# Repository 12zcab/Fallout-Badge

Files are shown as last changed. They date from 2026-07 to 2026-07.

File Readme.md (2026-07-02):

# Soupa Cool Badge for FallOut:D

Erm yah why not build a Badge with Z80 instead of ESP32 :)

Slack Username:12zcab

# What it can do?

1.Display ur Detail on 1602 LCD

2.use joystick and 6 Buttons to control the device

3.Plug it onto ur computer and have more interaction through console!

AND THE MOST IMPORTANT POINT IS: ITS HACKABLE!!!!!!!!!

U can easily reprogram it by overriding data on the EEPROM

# Main Components
Pls refer to BOM.csv for more details
1.Z80 10MHz
2.Z80 PIO 10MHz IC
3.MS6850 Serial IC
4.WC1602A LCD Display
5.Push Buttons
6.5 Direction Mini Joystick
7.on Board CH340

# Images

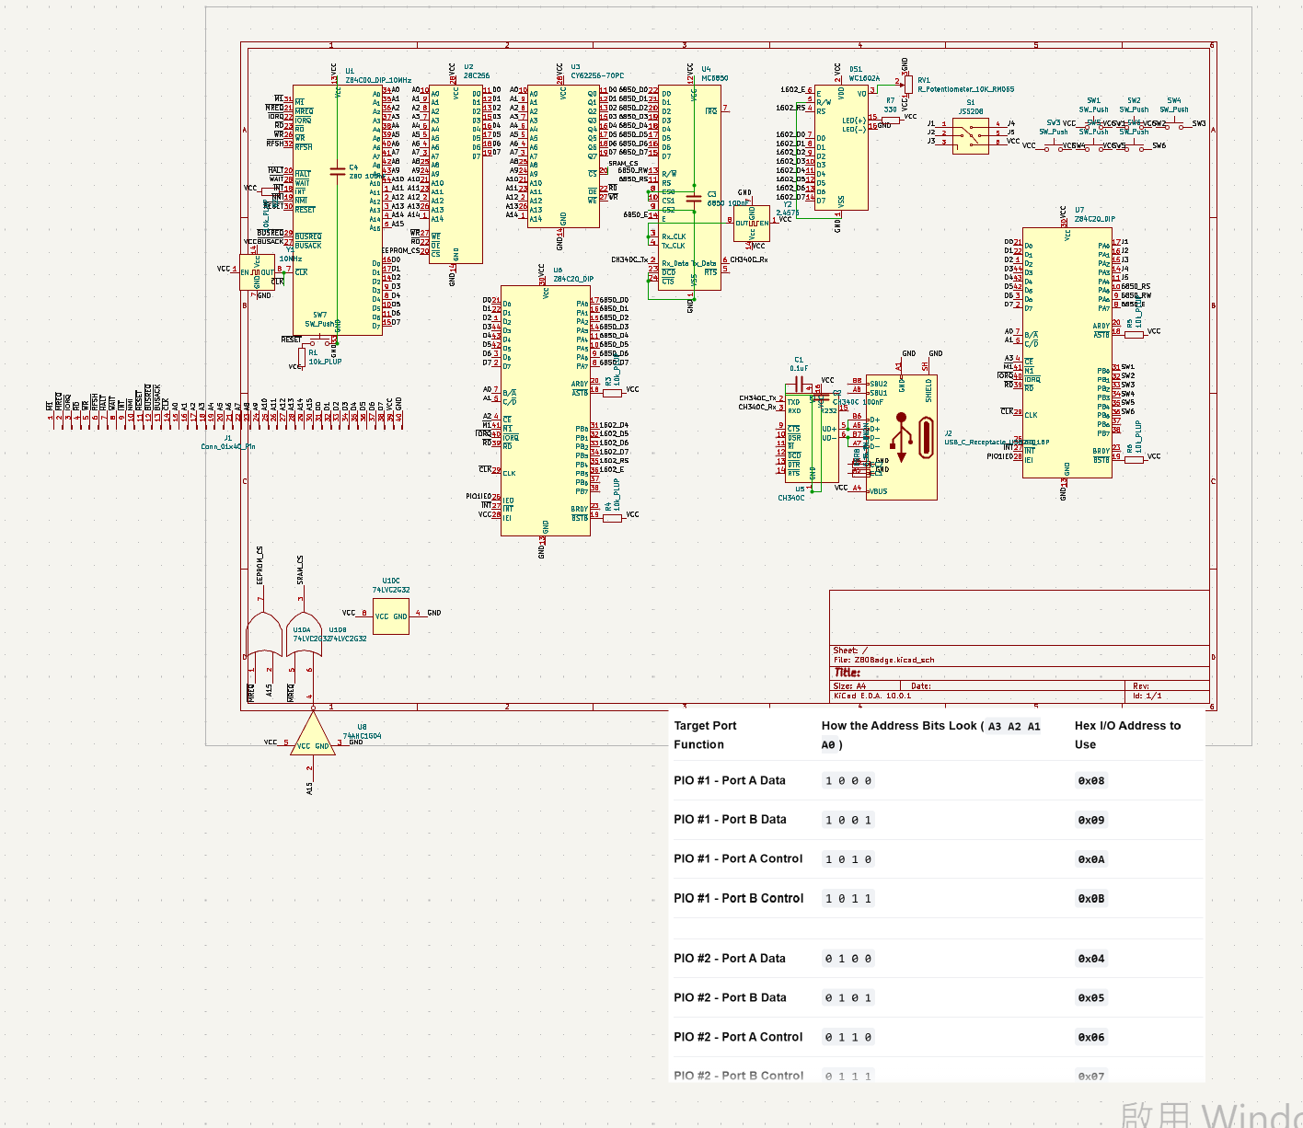
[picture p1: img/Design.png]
Design


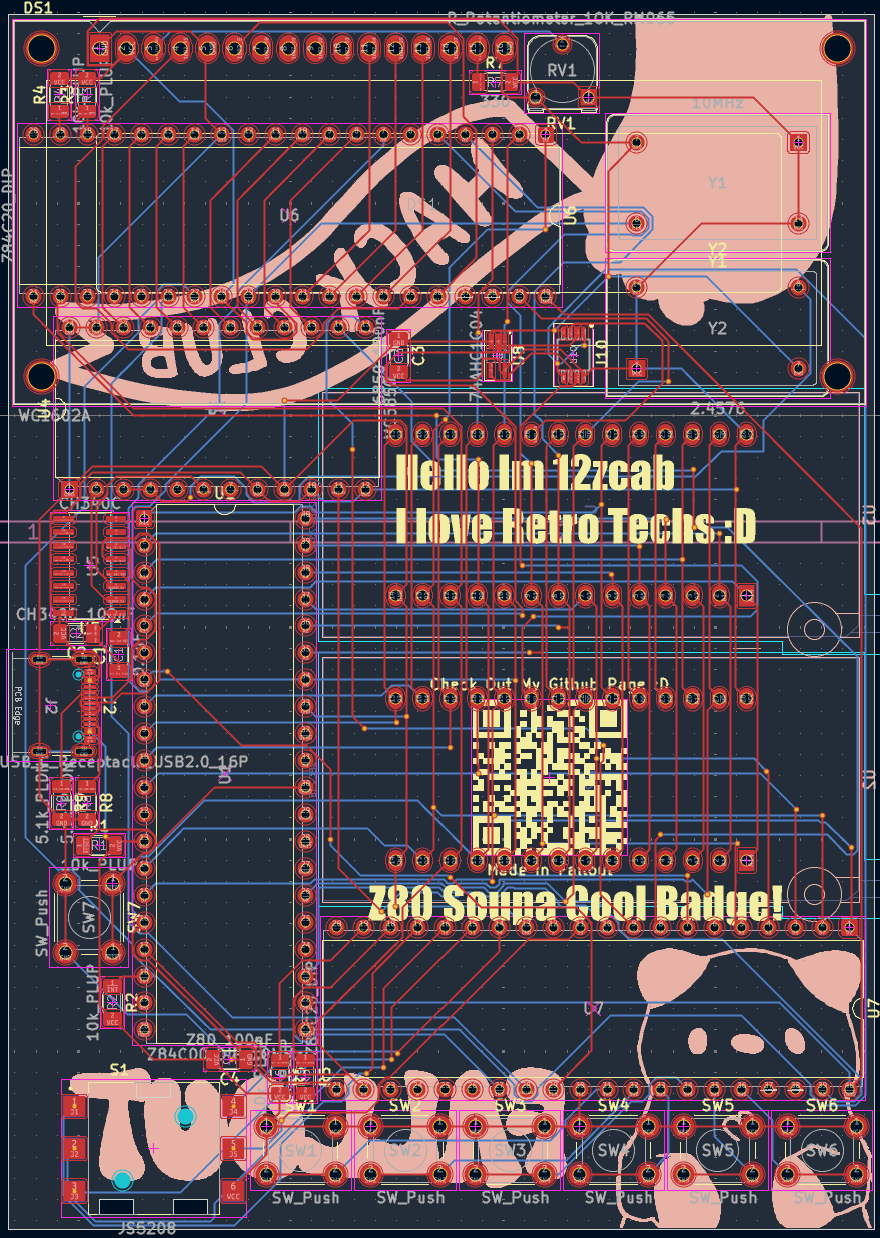
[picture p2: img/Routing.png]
Routing


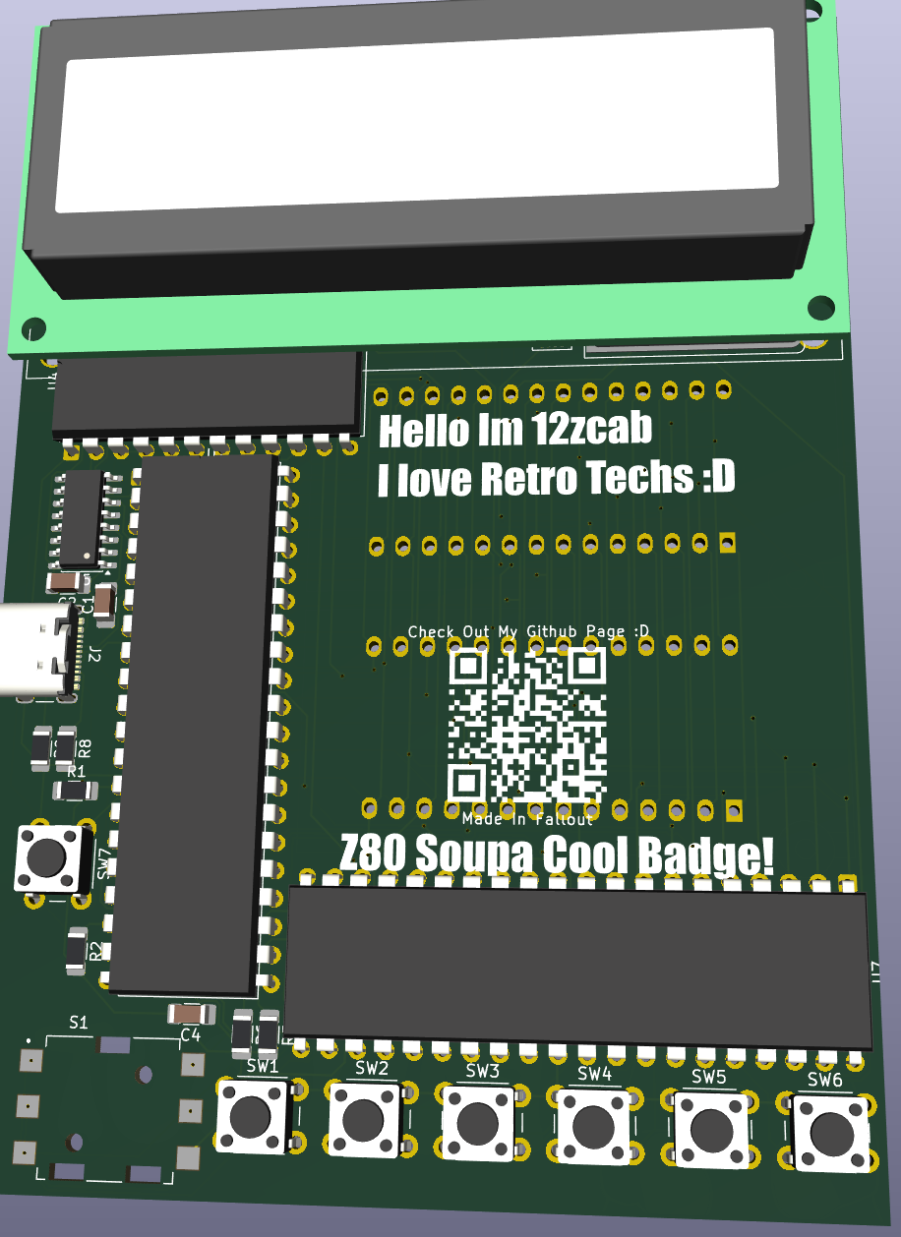
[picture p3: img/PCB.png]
PCB


PCB-Order-Page

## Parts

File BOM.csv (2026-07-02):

Item Name | Item Quantity | Item Link | Item Unit Price | Item Price(RMB) | Price In USD
Capa 100nF 1206 | 4 | https://detail.tmall.com/item.htm?id=592764875280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 | NOT APPLIABLE | 4.95
WC1602A | 1 | https://item.taobao.com/item.htm?ali_trackid=282_47943c4e9544049cca0f72b199db7b70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 | NOT APPLIABLE | 5.3
USB C 6P SMD | 1 | https://item.taobao.com/item.htm?id=990070098529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 | 4.8 | 4.8
Resis 10k 1206 | 6 | https://item.taobao.com/item.htm?id=948014405380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 | NOT APPLIABLE | 1.5
Resis 330 1206 | 1 | https://item.taobao.com/item.htm?id=948014405380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 | NOT APPLIABLE | 1.5
Resis 5.1k 1206 | 2 | https://item.taobao.com/item.htm?id=948014405380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 | NOT APPLIABLE | 1.5
RM065 Potentio SMD 10k | 1 | https://item.taobao.com/item.htm?ali_trackid=282_178754382f306b094bdb580dd3a8b003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 | 1.4 | 1.4
JS5208 | 1 | https://item.taobao.com/item.htm?id=739043147728&skuId=5096271028949 | 2.2 | 2.2
SW 6mm THT | 7 | https://item.taobao.com/item.htm?id=1021276117454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 | NOT APPLIABLE | 2.8
Z84C00 DIP | 1 | https://item.taobao.com/item.htm?id=608875850524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 | 4.5 | 4.5
28C256 DIP | 1 | https://item.taobao.com/item.htm?id=39532371153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 | 16.5 | 16.5
CY62256 DIP | 1 | https://item.taobao.com/item.htm?id=1048236230258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 | 4 | 4
MC6850 | 1 | https://item.taobao.com/item.htm?id=774768319105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 | 2.98 | 2.98
CH340C | 1 | https://detail.tmall.com/item.htm?id=969941374446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 | 2.2 | 2.2
Z84C20 DIP | 2 | https://item.taobao.com/item.htm?id=761218301763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 | 5.5 | 11
74AHC1G04 | 1 | https://item.taobao.com/item.htm?id=1056972037441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 | 0.26 | 0.26
74LVC2G32 | 1 | https://item.taobao.com/item.htm?ali_trackid=282_a1cc07042d99c9e791c237e71c7924dd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 | 1.08 | 1.08
10MHz Crystal | 1 | https://item.taobao.com/item.htm?id=594658769726&from=cart&skuId=4463870019686&upStreamPrice=495 | 4.95 | 4.95
2.4576 Crystal | 1 | https://item.taobao.com/item.htm?id=594658769726&from=cart&skuId=4463870019686&upStreamPrice=495 | 4.95 | 4.95
DIP Sockets | 2 | https://detail.tmall.com/item.htm?id=14119412637&skuId=5061116598157 | 4.27 | 8.54
OverAll |  |  |  | 86.91 | 13.0365
PCB |  |  |  | Dunno | Dunno

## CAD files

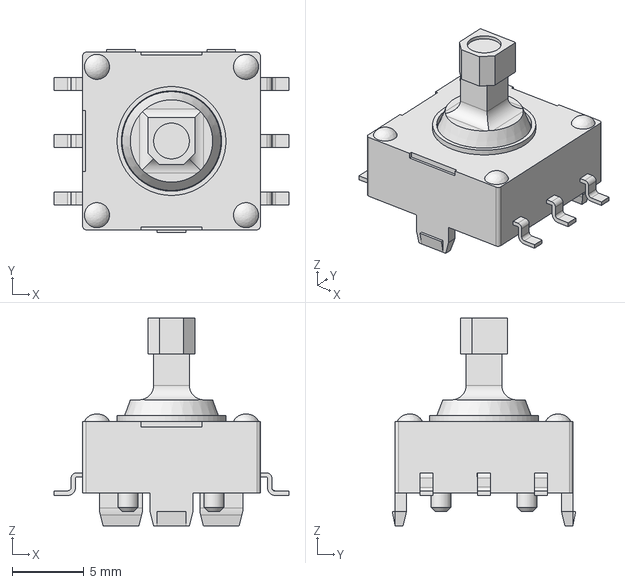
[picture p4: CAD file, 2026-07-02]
JS5208/JS5208.step
16.4 x 12.8 x 14.5 mm

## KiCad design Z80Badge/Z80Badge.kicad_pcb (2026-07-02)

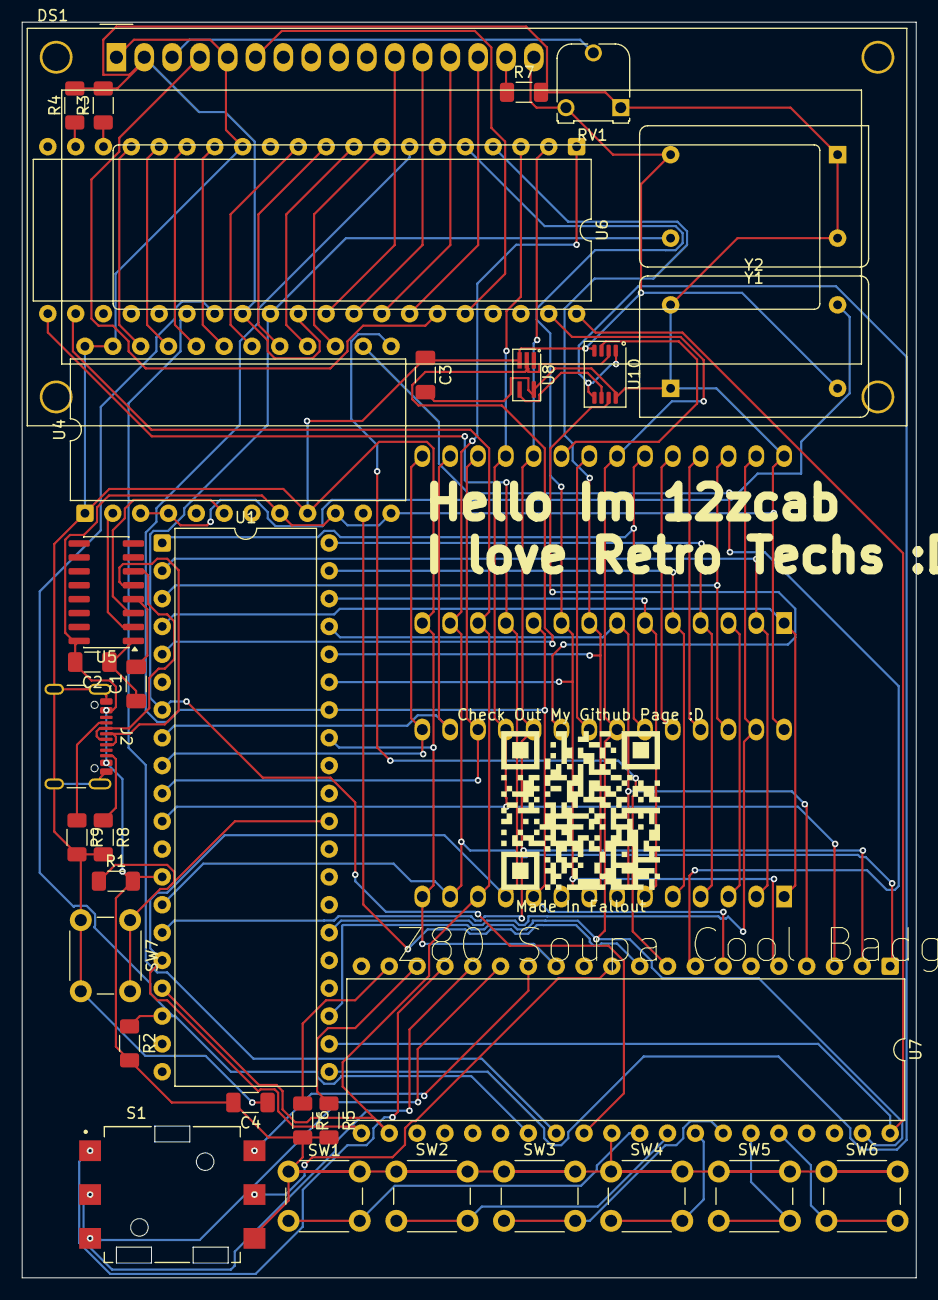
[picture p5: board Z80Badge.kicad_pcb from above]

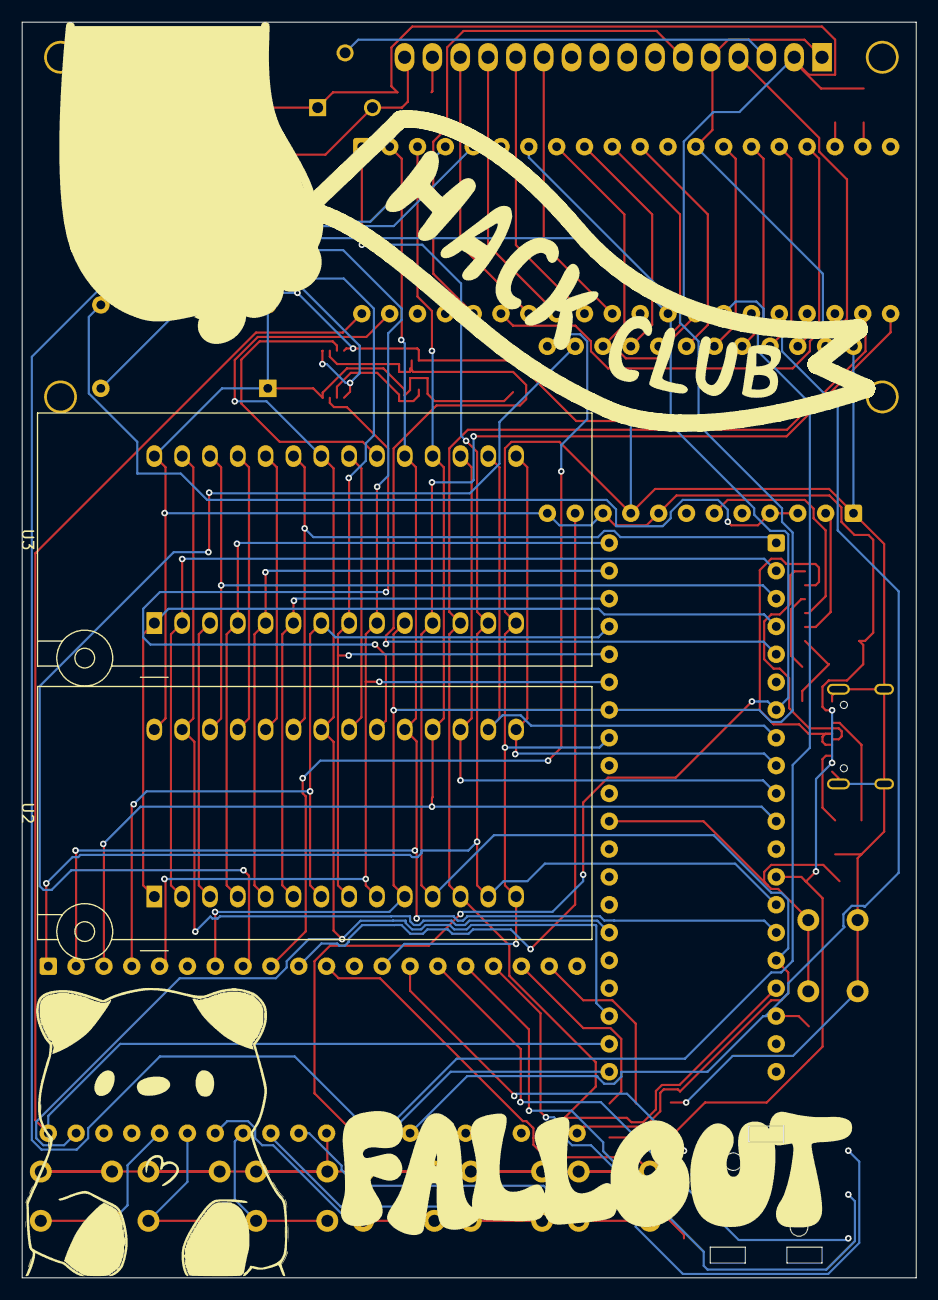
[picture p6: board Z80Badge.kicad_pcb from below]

Board: 2 copper layers, 81.6 x 114.6 mm, 36 parts (2 on the bottom side), 80 nets.

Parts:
C1: 0.1uF; C_1206_3216Metric_Pad1.33x1.80mm_HandSolder
C2: CH340C 100nF; C_1206_3216Metric_Pad1.33x1.80mm_HandSolder
C3: 6850 100nF; C_1206_3216Metric_Pad1.33x1.80mm_HandSolder
C4: Z80 100nF; C_1206_3216Metric_Pad1.33x1.80mm_HandSolder
DS1: WC1602A
J2: USB_C_Receptacle_USB2.0_16P; USB_C_Receptacle_GCT_USB4105-xx-A_16P_TopMnt_Horizontal
Made In Fallout: Check Out My Github Page :D; //github.com/12zcab?tab=repositories
R1, R2, R3, R4, R5, R6: 10k_PLUP; R_1206_3216Metric_Pad1.30x1.75mm_HandSolder
R7: 330; R_1206_3216Metric_Pad1.30x1.75mm_HandSolder
R8, R9: 5.1k_PLDN; R_1206_3216Metric_Pad1.30x1.75mm_HandSolder
RV1: R_Potentiometer_10K_RM065; Potentiometer_Runtron_RM-065_Vertical
S1: JS5208; SW_JS5208
SW1, SW2, SW3, SW4, SW5, SW6, SW7: SW_Push; SW_PUSH_6mm
U1: Z84C00_DIP_10MHz; DIP-40_W15.24mm
U2: 28C256; DIP_Socket-28_W11.9mm_W12.7mm_W15.24mm_W17.78mm_W18.5mm_3M_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
U3: CY62256-70PC; DIP_Socket-28_W11.9mm_W12.7mm_W15.24mm_W17.78mm_W18.5mm_3M_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
U4: MC6850; DIP-24_W15.24mm
U5: CH340C; SOIC-16_3.9x9.9mm_P1.27mm
U6, U7: Z84C20_DIP; DIP-40_W15.24mm
U8: 74AHC1G04; SOT-353_SC-70-5_Handsoldering
U10: 74LVC2G32; TSSOP-8_3x3mm_P0.65mm
Y1: 10MHz; Oscillator_DIP-14
Y2: 2.4576; Oscillator_DIP-14

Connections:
/1602_D4: DS1.11 (D4), U6.31 (PB_{0})
/1602_D5: DS1.12 (D5), U6.32 (PB_{1})
/1602_D6: DS1.13 (D6), U6.33 (PB_{2})
/1602_D7: DS1.14 (D7), U6.34 (PB_{3})
/1602_E: DS1.6 (E), U6.36 (PB_{5})
/1602_RS: DS1.4 (RS), U6.35 (PB_{4})
/6850_D0: U4.22 (D0), U6.17 (PA_{0})
/6850_D1: U4.21 (D1), U6.16 (PA_{1})
/6850_D2: U4.20 (D2), U6.15 (PA_{2})
/6850_D3: U4.19 (D3), U6.14 (PA_{3})
/6850_D4: U4.18 (D4), U6.11 (PA_{4})
/6850_D5: U4.17 (D5), U6.10 (PA_{5})
/6850_D6: U4.16 (D6), U6.9 (PA_{6})
/6850_D7: U4.15 (D7), U6.8 (PA_{7})
/6850_E: U4.14 (E), U7.8 (PA_{7})
/6850_RS: U4.11 (RS), U7.10 (PA_{5})
/6850_RW: U4.13 (R/~W), U7.9 (PA_{6})
/A0: U1.34 (A_{0}), U2.10 (A0), U3.10 (A0), U6.7 (B/~A), U7.7 (B/~A)
/A1: U1.35 (A_{1}), U2.9 (A1), U3.9 (A1), U6.5 (C/~D), U7.5 (C/~D)
/A2: U1.36 (A_{2}), U2.8 (A2), U3.8 (A2), U6.4 (~CE)
/A3: U1.37 (A_{3}), U2.7 (A3), U3.7 (A3), U7.4 (~CE)
/A4: U1.38 (A_{4}), U2.6 (A4), U3.6 (A4)
/A5: U1.39 (A_{5}), U2.5 (A5), U3.5 (A5)
/A6: U1.40 (A_{6}), U2.4 (A6), U3.4 (A6)
/A7: U2.3 (A7), U3.3 (A7)
/A8: U2.25 (A8), U3.25 (A8)
/A9: U2.24 (A9), U3.24 (A9)
/A10: U2.21 (A10), U3.21 (A10)
/A11: U1.1 (A_{11}), U2.23 (A11), U3.23 (A11)
/A12: U1.2 (A_{12}), U2.2 (A12), U3.2 (A12)
/A13: U1.3 (A_{13}), U2.26 (A13), U3.26 (A13)
/A14: U1.4 (A_{14}), U2.1 (A14), U3.1 (A14)
/A15: U1.5 (A_{15}), U8.2, U10.2
/CH340C_Rx: U4.6 (Tx_Data), U5.3 (RXD)
/CH340C_Tx: U4.2 (Rx_Data), U5.2 (TXD)
/D0: U1.16 (D_{0}), U2.11 (D0), U3.11 (Q0), U6.21 (D_{0}), U7.21 (D_{0})
/D1: U1.17 (D_{1}), U2.12 (D1), U3.12 (Q1), U6.22 (D_{1}), U7.22 (D_{1})
/D2: U1.14 (D_{2}), U2.13 (D2), U3.13 (Q2), U6.1 (D_{2}), U7.1 (D_{2})
/D3: U1.9 (D_{3}), U2.15 (D3), U3.15 (Q3)
/D4: U1.8 (D_{4}), U2.16 (D4), U3.16 (Q4)
/D5: U1.10 (D_{5}), U2.17 (D5), U3.17 (Q5)
/D6: U1.11 (D_{6}), U2.18 (D6), U3.18 (Q6), U6.3 (D_{6}), U7.3 (D_{6})
/D7: U1.15 (D_{7}), U2.19 (D7), U3.19 (Q7), U6.2 (D_{7}), U7.2 (D_{7})
/EEPROM_CS: U2.20 (~CS), U10.7
/GND: C3.1, C4.1, DS1.1 (VSS), DS1.5 (R/W), DS1.16 (LED(-)), J2.A1 (GND), J2.A12 (GND), J2.B1 (GND), J2.B12 (GND), J2.SH (SHIELD), R8.2, R9.2, RV1.3, SW7.2, U1.33 (GND), U2.14 (GND), U3.14 (GND), U4.1 (VSS), U4.9 (CS2), U4.23 (~DCD), U4.24 (~CTS), U6.13 (GND), U7.13 (GND), U8.3 (GND), U10.4 (GND), Y1.7 (GND), Y2.7 (GND)
/J1: S1.1, U7.17 (PA_{0})
/J2: S1.2, U7.16 (PA_{1})
/J3: S1.3, U7.15 (PA_{2})
/J4: S1.4, U7.14 (PA_{3})
/J5: S1.5, U7.11 (PA_{4})
/PIO1IE0: U6.26 (IEO), U7.28 (IEI)
/SRAM_CS: U3.20 (~CS), U10.3
/SW1: SW1.2, U7.31 (PB_{0})
/SW2: SW2.2, U7.32 (PB_{1})
/SW3: SW4.2, U7.33 (PB_{2})
/SW4: SW3.2, U7.34 (PB_{3})
/SW5: SW5.2, U7.35 (PB_{4})
/SW6: SW6.2, U7.36 (PB_{5})
/VCC: C2.2, C3.2, C4.2, DS1.2 (VDD), J2.A4 (VBUS), J2.A9 (VBUS), J2.B4 (VBUS), J2.B9 (VBUS), R1.2, R2.2, R3.2, R4.2, R5.2, R6.2, R7.2, RV1.1, S1.6, SW1.1, SW2.1, SW3.1, SW4.1, SW5.1, SW6.1, U1.13 (V_{CC}), U2.28 (VCC), U3.28 (VCC), U4.8 (CS0), U4.10 (CS1), U4.12 (VCC), U5.16 (VCC), U6.28 (IEI), U6.30 (V_{CC}), U7.30 (V_{CC}), U8.5 (VCC), U10.8 (VCC), Y1.1 (EN), Y1.14 (Vcc), Y2.1 (EN), Y2.14 (Vcc)
/~CLK: U1.7 (~CLK), U6.29 (CLK), U7.29 (CLK), Y1.8 (OUT)
/~INT: R2.1, U1.18 (~INT), U6.27 (~INT), U7.27 (~INT)
/~IORQ: U1.22 (~IORQ), U6.40 (~IORQ), U7.40 (~IORQ)
/~MREQ: U1.21 (~MREQ), U10.1, U10.5
/~RD: U1.23 (~RD), U2.22 (~OE), U3.22 (~OE), U6.39 (~RD), U7.39 (~RD)
/~RESET: R1.1, SW7.1, U1.30 (~RESET)
/~WR: U1.26 (~WR), U2.27 (~WE), U3.27 (~WE)
unnamed: DS1.15 (LED(+)), R7.1
unnamed: DS1.3 (VO), RV1.2
unnamed: J2.A5 (CC1), R9.1
unnamed: J2.B5 (CC2), R8.1
unnamed: U4.3 (Rx_CLK), U4.4 (Tx_CLK), Y2.8 (OUT)
unnamed: C1.1, C2.1, U5.1 (GND)
unnamed: J2.A6 (D+), J2.B6 (D+), U5.5 (UD+)
unnamed: J2.A7 (D-), J2.B7 (D-), U5.6 (UD-)
unnamed: C1.2, U5.4 (V3)
unnamed: R3.1, U6.18 (~ASTB)
unnamed: R4.1, U6.19 (~BSTB)
unnamed: R5.1, U7.18 (~ASTB)
unnamed: R6.1, U7.19 (~BSTB)
unnamed: U8.4, U10.6
